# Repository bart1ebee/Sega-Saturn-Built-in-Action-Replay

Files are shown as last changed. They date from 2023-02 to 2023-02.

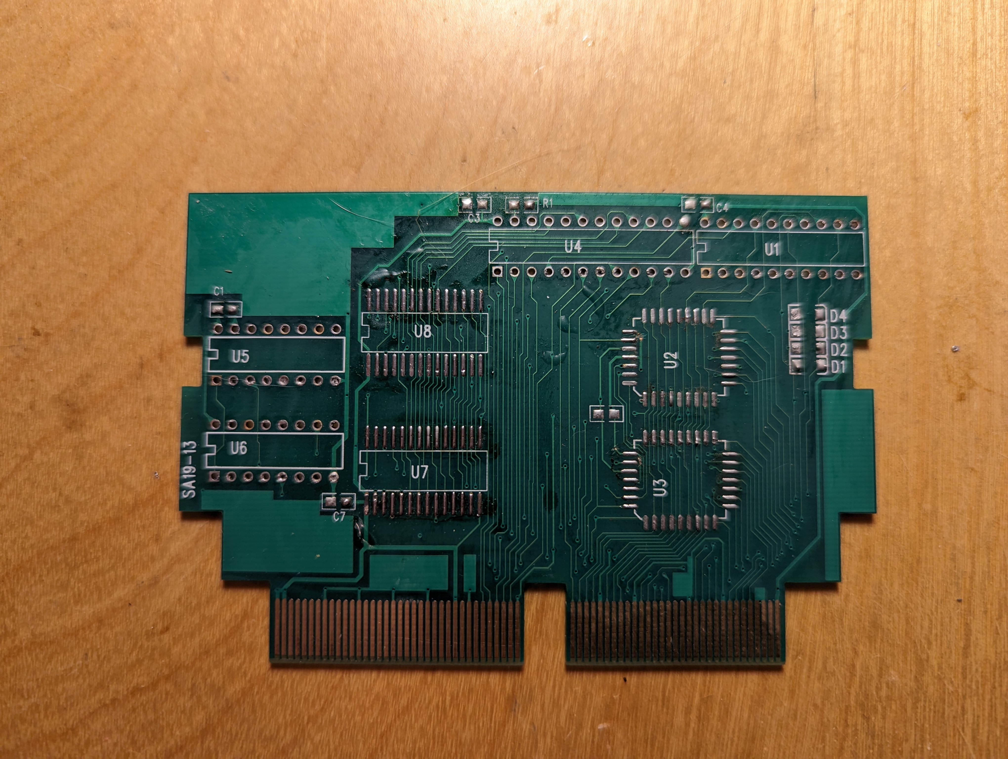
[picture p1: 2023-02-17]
Photos/Action Replay Board.jpg

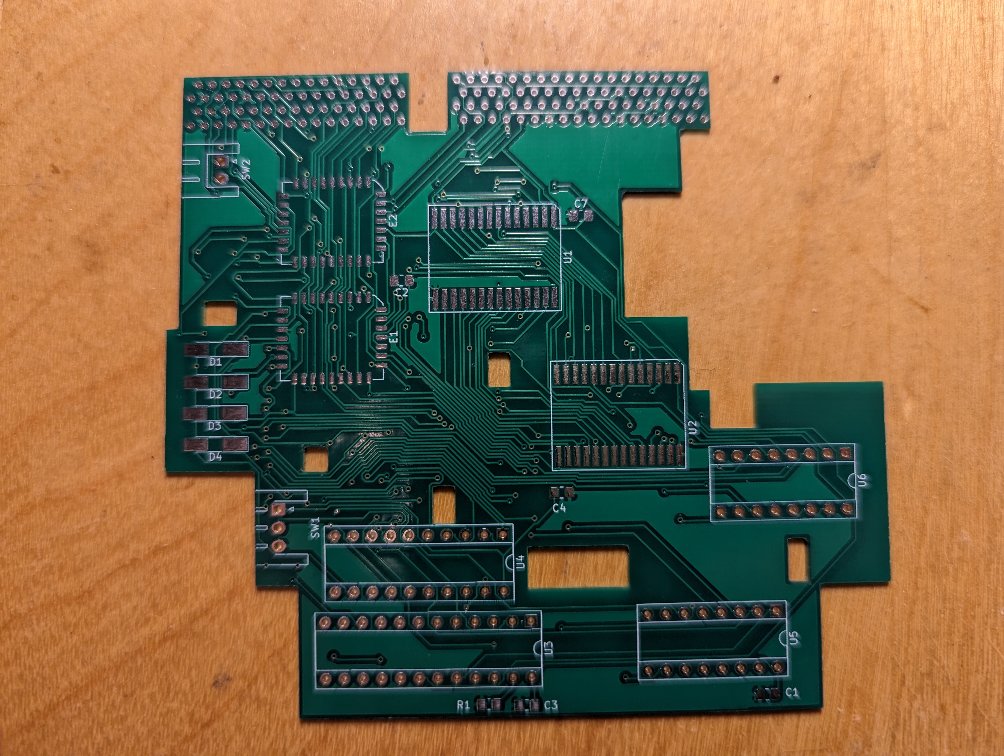
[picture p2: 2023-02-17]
Photos/Action Reply builtin.jpg

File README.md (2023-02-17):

# Sega-Saturn-Built-in-Action-Replay

This will allow you to take an action replay for a Sega Saturn and solder it to the under side of the cart connector to bypass a bad slot.

This currently is setup to work with VA 0 and .5 motherboards I believe it will work with VA1 but do not have a system to test with. In the future I'd like to make the same board or possibly a few boards for all revisions.

## Features

- Enable / Disable with a switch
- Swap between Action Replay and [Pseudo Saturn Kai](https://ppcenter.webou.net/pskai/)
- If PAL equations can be extracted this could be buildable without buying an action replay 

## Parts Needed

- PCB
- Action Replay containing the following
    - 2x HM5117800J
    - 2x sst29ee020-120-4c-nh
    - 2x 74157
    - PAL16L8 
    - PAL24
- Soldering skills
- Optional: the STL folder has a fake cart slot with catches to hold the Action Replay Cart that I added switches to.

## Building

1. Order Boards from a PCB supplier
2. Disassemble an Action replay and assemble on new board
3. SW1 is a SPDT On-On switch and SW2 is a SPST switch On-Off
4. Solder to underside of card slot

## Help Wanted

 Anyone that can extract the logic equations from the PAL Chips.

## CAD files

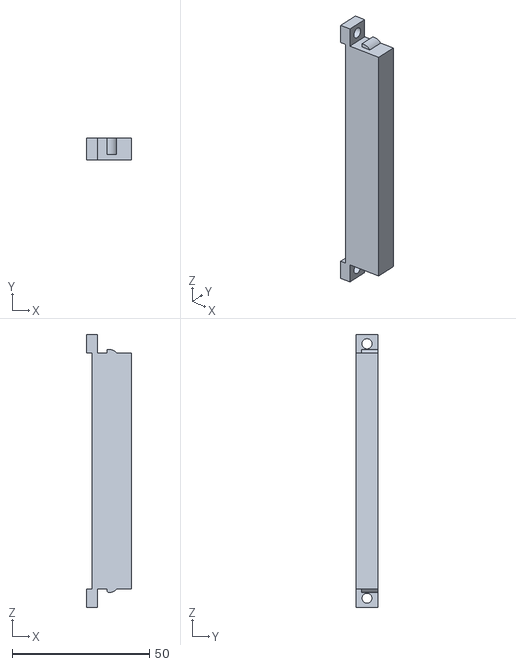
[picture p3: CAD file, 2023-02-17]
STL/sega cart v3.stl
16.4 x 8.11 x 99.5

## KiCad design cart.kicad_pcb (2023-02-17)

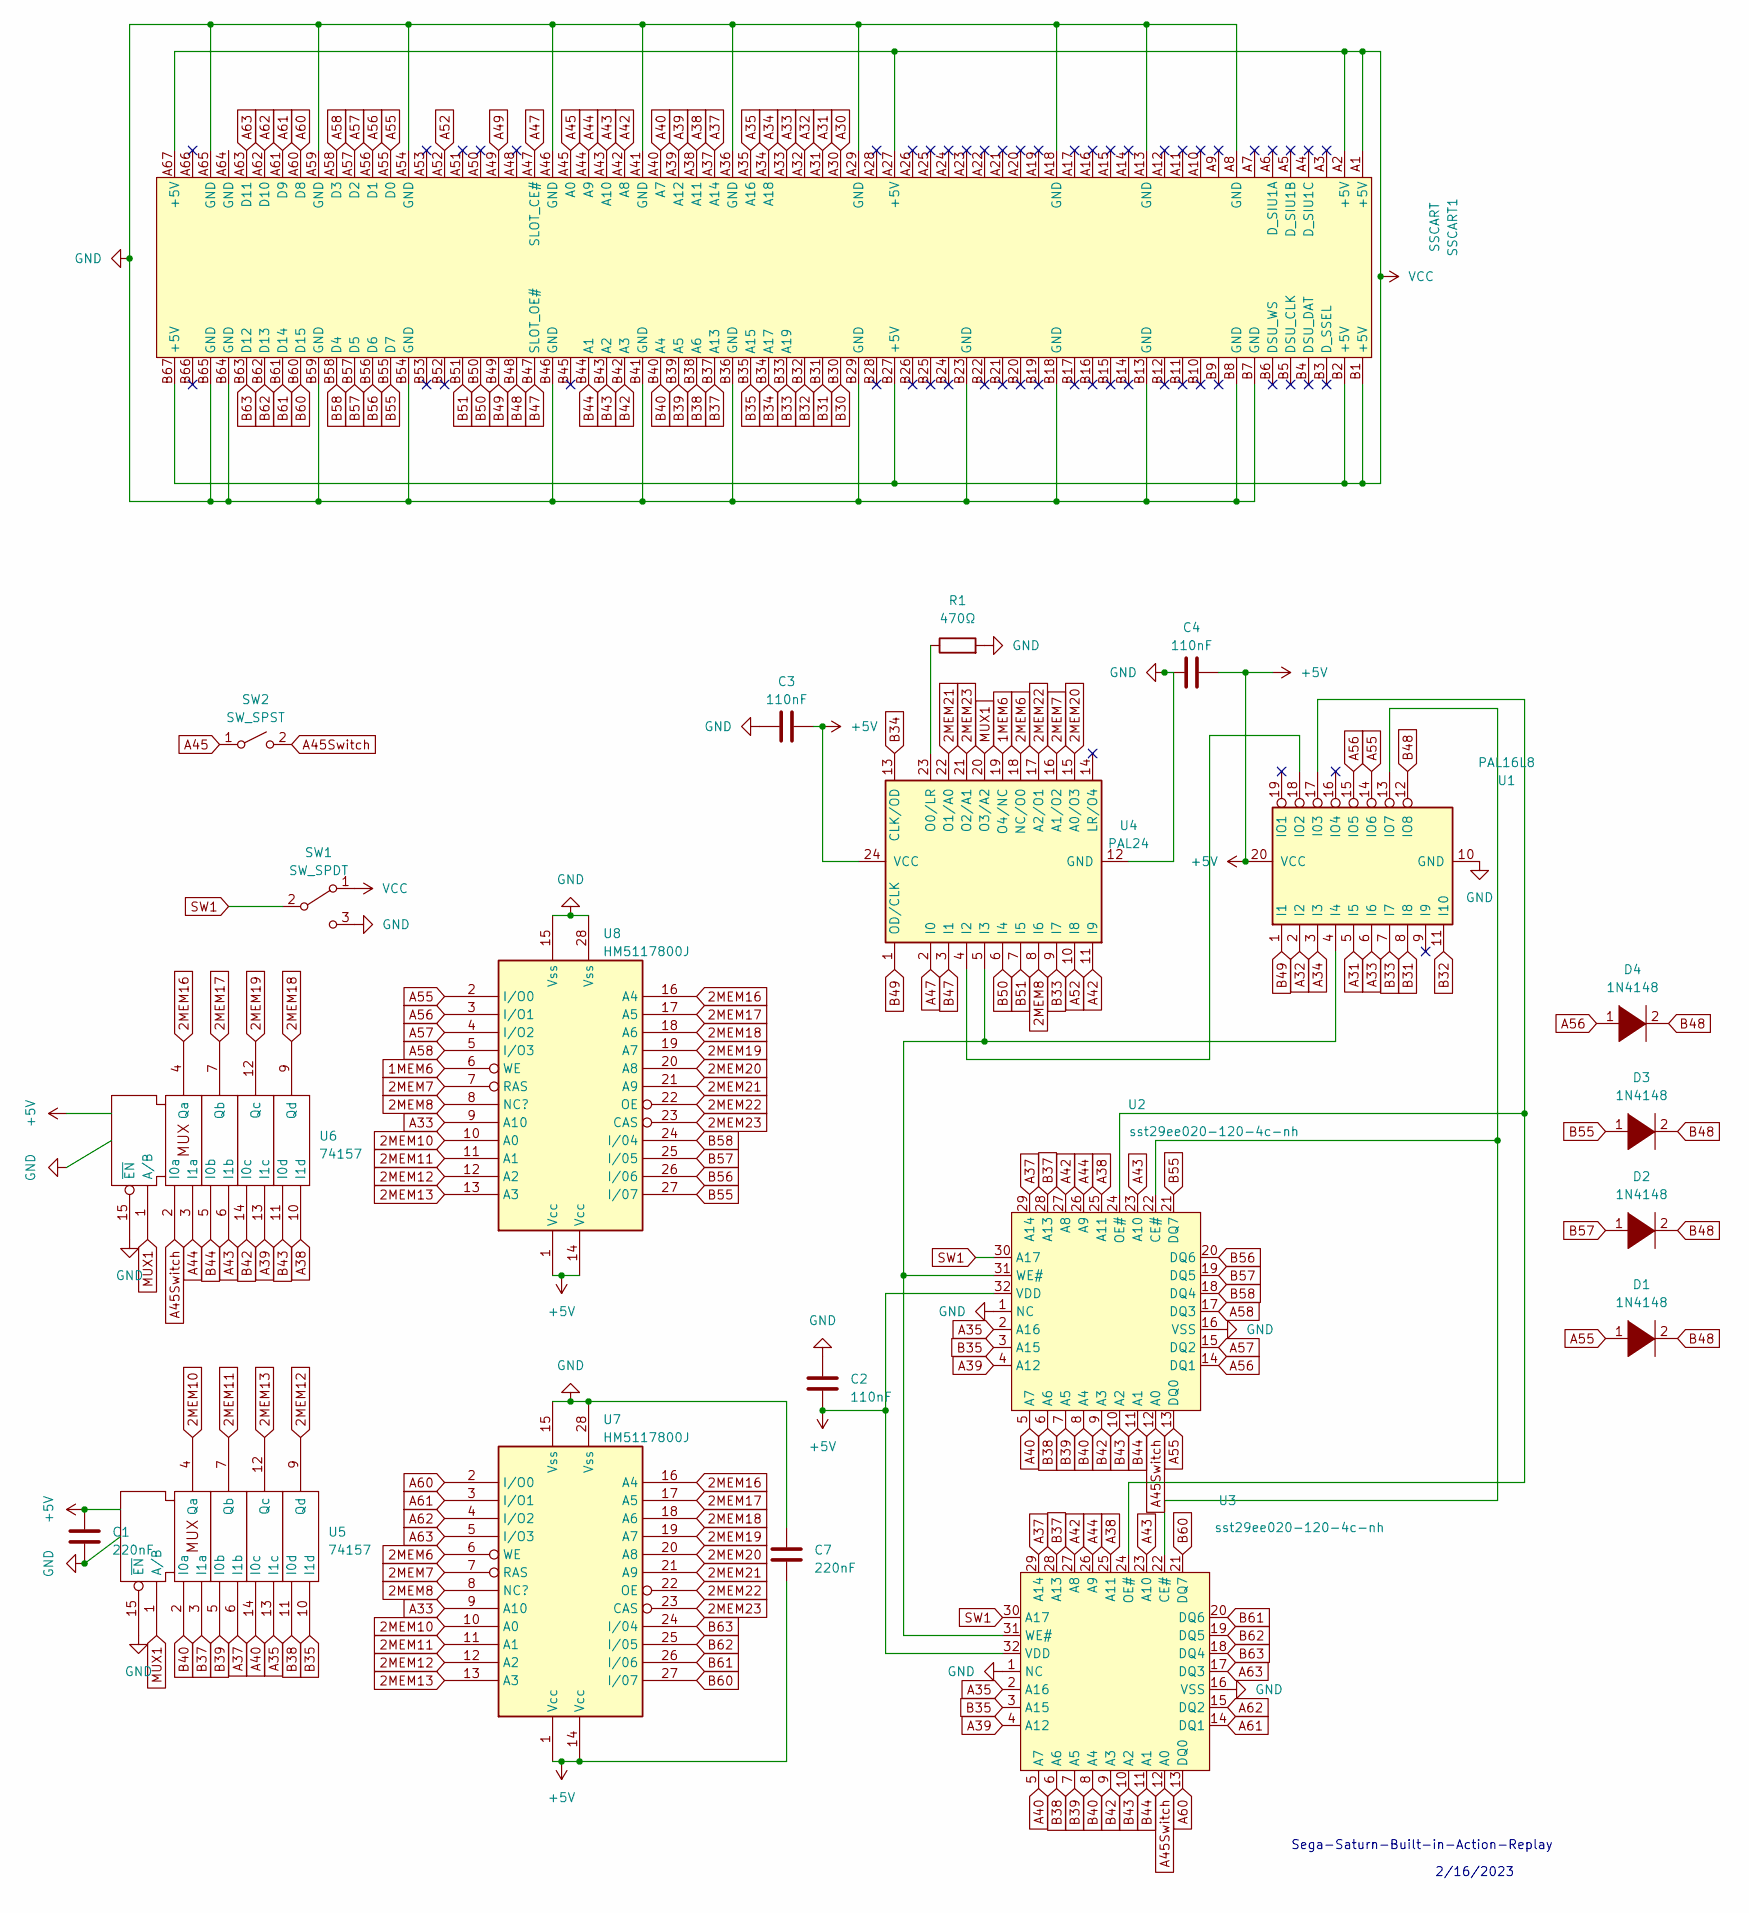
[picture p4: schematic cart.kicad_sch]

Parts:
C1, C7: 220nF; C_0805_2012Metric_Pad1.18x1.45mm_HandSolder
C2, C3, C4: 110nF; C_0805_2012Metric_Pad1.18x1.45mm_HandSolder
D1, D2, D3, D4: 1N4148; D_MiniMELF_Handsoldering
R1: 470Ω; R_0805_2012Metric_Pad1.20x1.40mm_HandSolder
SSCART1: SSCART; Sega Cart
SW1: SW_SPDT; JST_XH_S3B-XH-A-1_1x03_P2.50mm_Horizontal
SW2: SW_SPST; JST_XH_S2B-XH-A_1x02_P2.50mm_Horizontal
U1: PAL16L8; DIP-20_W7.62mm_Socket
U2, U3: sst29ee020-120-4c-nh; PLCC-32_11.4x14.0mm_P1.27mm
U4: PAL24; DIP-24_W7.62mm_Socket
U5, U6: 74157; DIP-16_W7.62mm_Socket
U7, U8: HM5117800J; SOIC-28

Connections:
1MEM6: U4.19 (O4/NC), U8.6 (WE)
2MEM6: U4.18 (NC/O0), U7.6 (WE)
2MEM7: U4.16 (A1/O2), U7.7 (RAS), U8.7 (RAS)
2MEM8: U4.8 (I6), U7.8 (NC?), U8.8 (NC?)
2MEM10: U5.4 (Qa), U7.10 (A0), U8.10 (A0)
2MEM11: U5.7 (Qb), U7.11 (A1), U8.11 (A1)
2MEM12: U5.9 (Qd), U7.12 (A2), U8.12 (A2)
2MEM13: U5.12 (Qc), U7.13 (A3), U8.13 (A3)
2MEM16: U6.4 (Qa), U7.16 (A4), U8.16 (A4)
2MEM17: U6.7 (Qb), U7.17 (A5), U8.17 (A5)
2MEM18: U6.9 (Qd), U7.18 (A6), U8.18 (A6)
2MEM19: U6.12 (Qc), U7.19 (A7), U8.19 (A7)
2MEM20: U4.15 (A0/O3), U7.20 (A8), U8.20 (A8)
2MEM21: U4.22 (O1/A0), U7.21 (A9), U8.21 (A9)
2MEM22: U4.17 (A2/O1), U7.22 (OE), U8.22 (OE)
2MEM23: U4.21 (O2/A1), U7.23 (CAS), U8.23 (CAS)
A30: SSCART1.A30
A31: SSCART1.A31, U1.5 (I5)
A32: SSCART1.A32, U1.2 (I2)
A33: SSCART1.A33, U1.6 (I6), U7.9 (A10), U8.9 (A10)
A34: SSCART1.A34 (A18), U1.3 (I3)
A35: SSCART1.A35 (A16), U2.2 (A16), U3.2 (A16), U5.13 (I1c)
A37: SSCART1.A37 (A14), U2.29 (A14), U3.29 (A14), U5.6 (I1b)
A38: SSCART1.A38 (A11), U2.25 (A11), U3.25 (A11), U6.10 (I1d)
A39: SSCART1.A39 (A12), U2.4 (A12), U3.4 (A12), U6.13 (I1c)
A40: SSCART1.A40 (A7), U2.5 (A7), U3.5 (A7), U5.14 (I0c)
A42: SSCART1.A42 (A8), U2.27 (A8), U3.27 (A8), U4.11 (I9)
A43: SSCART1.A43 (A10), U2.23 (A10), U3.23 (A10), U6.6 (I1b)
A44: SSCART1.A44 (A9), U2.26 (A9), U3.26 (A9), U6.3 (I1a)
A45: SSCART1.A45 (A0), SW2.1 (A)
A45Switch: SW2.2 (B), U2.12 (A0), U3.12 (A0), U6.2 (I0a)
A47: SSCART1.A47 (SLOT_CE#), U4.2 (I0)
A49: SSCART1.A49
A52: SSCART1.A52, U4.10 (I8)
A55: D1.1 (K), SSCART1.A55 (D0), U1.14 (IO6), U2.13 (DQ0), U8.2 (I/O0)
A56: D4.1 (K), SSCART1.A56 (D1), U1.15 (IO5), U2.14 (DQ1), U8.3 (I/O1)
A57: SSCART1.A57 (D2), U2.15 (DQ2), U8.4 (I/O2)
A58: SSCART1.A58 (D3), U2.17 (DQ3), U8.5 (I/O3)
A60: SSCART1.A60 (D8), U3.13 (DQ0), U7.2 (I/O0)
A61: SSCART1.A61 (D9), U3.14 (DQ1), U7.3 (I/O1)
A62: SSCART1.A62 (D10), U3.15 (DQ2), U7.4 (I/O2)
A63: SSCART1.A63 (D11), U3.17 (DQ3), U7.5 (I/O3)
B30: SSCART1.B30
B31: SSCART1.B31, U1.8 (I8)
B32: SSCART1.B32, U1.11 (I10)
B33: SSCART1.B33 (A19), U1.7 (I7), U4.9 (I7)
B34: SSCART1.B34 (A17), U4.13 (CLK/OD)
B35: SSCART1.B35 (A15), U2.3 (A15), U3.3 (A15), U5.10 (I1d)
B37: SSCART1.B37 (A13), U2.28 (A13), U3.28 (A13), U5.3 (I1a)
B38: SSCART1.B38 (A6), U2.6 (A6), U3.6 (A6), U5.11 (I0d)
B39: SSCART1.B39 (A5), U2.7 (A5), U3.7 (A5), U5.5 (I0b)
B40: SSCART1.B40 (A4), U2.8 (A4), U3.8 (A4), U5.2 (I0a)
B42: SSCART1.B42 (A3), U2.9 (A3), U3.9 (A3), U6.14 (I0c)
B43: SSCART1.B43 (A2), U2.10 (A2), U3.10 (A2), U6.11 (I0d)
B44: SSCART1.B44 (A1), U2.11 (A1), U3.11 (A1), U6.5 (I0b)
B47: SSCART1.B47 (SLOT_OE#), U4.3 (I1)
B48: D1.2 (A), D2.2 (A), D3.2 (A), D4.2 (A), SSCART1.B48, U1.12 (IO8)
B49: SSCART1.B49, U1.1 (I1), U4.1 (OD/CLK)
B50: SSCART1.B50, U4.6 (I4)
B51: SSCART1.B51, U4.7 (I5)
B55: D3.1 (K), SSCART1.B55 (D7), U2.21 (DQ7), U8.27 (I/07)
B56: SSCART1.B56 (D6), U2.20 (DQ6), U8.26 (I/06)
B57: D2.1 (K), SSCART1.B57 (D5), U2.19 (DQ5), U8.25 (I/05)
B58: SSCART1.B58 (D4), U2.18 (DQ4), U8.24 (I/04)
B60: SSCART1.B60 (D15), U3.21 (DQ7), U7.27 (I/07)
B61: SSCART1.B61 (D14), U3.20 (DQ6), U7.26 (I/06)
B62: SSCART1.B62 (D13), U3.19 (DQ5), U7.25 (I/05)
B63: SSCART1.B63 (D12), U3.18 (DQ4), U7.24 (I/04)
GND: C1.2, C2.1, C3.2, C4.1, C7.1, R1.2, SSCART1.A8 (GND), SSCART1.A13 (GND), SSCART1.A18 (GND), SSCART1.A29 (GND), SSCART1.A36 (GND), SSCART1.A41 (GND), SSCART1.A46 (GND), SSCART1.A54 (GND), SSCART1.A59 (GND), SSCART1.A65 (GND), SSCART1.B7 (GND), SSCART1.B8 (GND), SSCART1.B13 (GND), SSCART1.B18 (GND), SSCART1.B23 (GND), SSCART1.B29 (GND), SSCART1.B36 (GND), SSCART1.B41 (GND), SSCART1.B46 (GND), SSCART1.B54 (GND), SSCART1.B59 (GND), SSCART1.B64 (GND), SSCART1.B65 (GND), SW1.3 (C), U1.10 (GND), U2.1 (NC), U2.16 (VSS), U3.1 (NC), U3.16 (VSS), U4.12 (GND), U5.8 (GND), U5.15 (~EN), U6.8 (GND), U6.15 (~EN), U7.15 (Vss), U7.28 (Vss), U8.15 (Vss), U8.28 (Vss)
MUX1: U4.20 (O3/A2), U5.1 (A/B), U6.1 (A/B)
unnamed: U1.17 (I03), U2.24 (OE#), U3.24 (OE#)
unnamed: U1.4 (I4), U2.31 (WE#), U3.31 (WE#), U4.5 (I3)
unnamed: U1.18 (IO2), U4.4 (I2)
unnamed: U1.13 (IO7), U2.22 (CE#), U3.22 (CE#)
unnamed: R1.1, U4.23 (O0/LR)
SW1: SW1.2 (B), U2.30 (A17), U3.30 (A17)

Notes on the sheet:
Sega-Saturn-Built-in-Action-Replay
2/16/2023

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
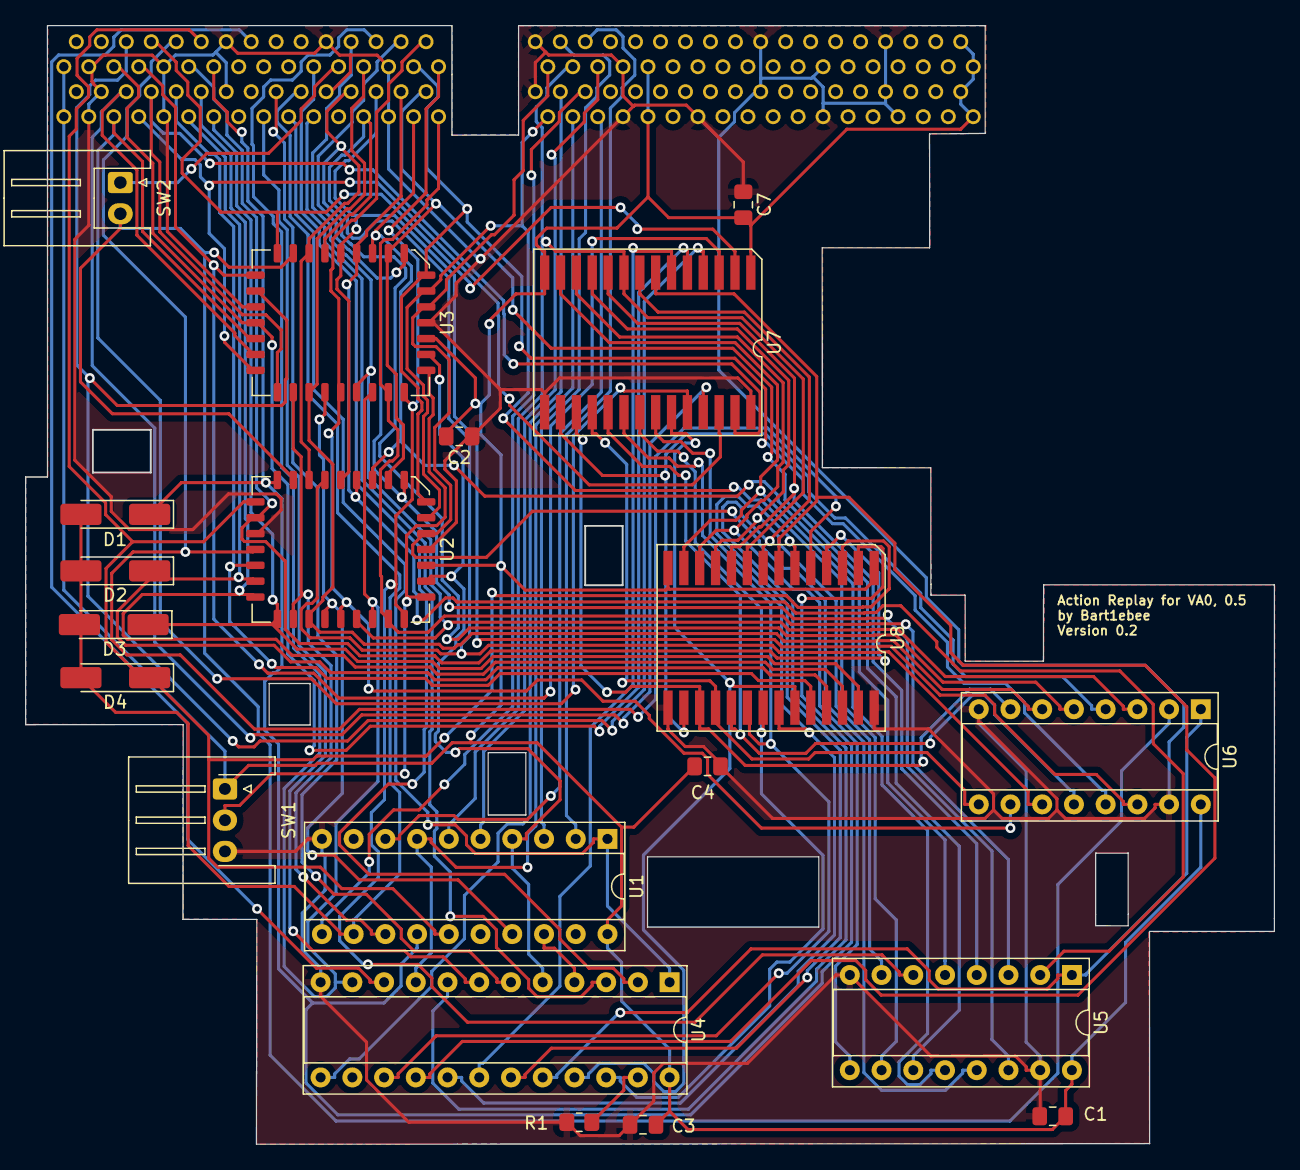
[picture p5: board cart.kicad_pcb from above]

Board: 2 copper layers, 100.0 x 89.6 mm, 21 parts (0 on the bottom side), 74 nets.
